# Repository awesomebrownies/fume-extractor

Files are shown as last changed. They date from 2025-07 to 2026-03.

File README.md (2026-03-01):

# Fume Extractor

A Travel packable fume-extractor for electronic prototyping inspired by Rogue One movie props. 

***Why?*** Many soldering iron fume extractors are low quality and merely push away fumes rather than properly filter them. The capsule design ensures that all air moves through a thick layer of **active carbon granules**, not some cheap foam. In addition, the HEPA filter will deal with any particulates that could irritate the lungs.

## Key Features

It provides **3 spares** of quick-swap carbon capsules with HEPA filters to provide **2 stage filtering**. The microcontroller has an external mount with warning lights when **failed filtering of Volatile Organic Compounds (VOCs)** is detected from a dedicated sensor. The vacuum tube is supported by a gooseneck arm for easily getting up close to fumes.

<p float="left">
  Screenshot from 2025-08-06 09-17-03
  Screenshot from 2025-07-29 23-48-41
</p>

## How to Assemble

There are two parts to this.
* Ordering BOM
* 3d Printing Parts (check CAD folder)
* Putting it all together

Let's skip over to putting it together.

### Wiring up the PWM fans to the Microcontroller (Rpi-Pico)

Refer to the wiring diagram below:

Screenshot from 2025-07-29 23-48-41

### Putting together the print

The capsules are in a couple of pieces, and you'll need a screw and a nut for each of the parts.

* First, insert the fan inside, with the wires on the accessible side for hooking up to the microcontroller. Use the screws available inside of the package for the fans
* Then, put a mesh between the fan and the rest of the capsule on the next part. You'll need two M2 screws and nuts
* Finally, pour the bag of carbon granules inside, and insert the HEPA filter at the end. As before, you'll need two M2 screws and nuts

### Final Steps

* Flashing firmware

To flash the firmware, open up the Arduino IDE, and copy and paste the code from the repository to the pico

## Project Bill of Materials

**Total Cost: $149.68**

## Electronics – $62.70

| Component | Quantity | Price | Link | Notes |
| --- | --- | ----- | --- | ----- |
| Air Quality Sensor | 1 | $6.20 | [DigiKey](https://www.digikey.com/en/products/detail/sensirion-ag/SGP40-D-R4/12820418) | |
| PWM Ventilation Fans | 3 | $48.00| [Amazon](https://www.amazon.com/Noctua-NF-A4x10-5V-PWM-Premium/dp/B07DXS86G7) | |
| Raspberry Pi Pico | 1 | $4.00 | [DigiKey](https://www.digikey.com/en/products/detail/raspberry-pi/SC0915/13684020) | |
| Rotary Encoder w/ Switch  | 1 | $4.50 | [DigiKey](https://www.digikey.com/en/products/detail/alps-alpine/EC11E09244BS/21721622) | |

## Fume Hood – $24.99

| Component | Quantity | Price  | Link | Notes |
| --- | --- | --- | --- | ----- |
| 19" Gooseneck Arm | 1 | $12.99 | [Amazon](https://www.amazon.com/Gator-Frameworks-Gooseneck-Microphones-GFW-MIC-GN19/dp/B01CUR5DU2) | |
| Flexible Hose | 1 | $12.00 | [Amazon](https://www.amazon.com/Flexible-Central-Vacuum-Installation-Hose/dp/B0CLH8M5JQ?source=ps-sl-shoppingads...) | |

## Filtering Elements – $61.99

| Component | Quantity | Price  | Link | Notes |
| --- | --- | --- | --- | ----- |
| Vacuum Washable HEPA Filter | 3 | $15.99 | [Amazon](https://www.amazon.com/SunSare-CPA1725-RYH-Vacuum-Filter-3PCS/dp/B0DQ8STYNL) | |
| Bag of Carbon Granules | 1 | $46.00 | [Amazon](https://www.amazon.com/AC-Infinity-Australian-Replacement-Hydroponics/dp/B0CFCKFPHR?th=1) | |

## Mechanics – $0.00

| Component | Quantity | Price | Link | Notes |
| ---| --- | ----- | ---- | --- |
| Springs | 2 | - | - | Already purchased |
| 3D Prints | - | - | - | Using printing legion  |
| Heatset M2 Inserts | 2  | - | - | Already purchased |

## Cost Summary

| Section | Cost |
| --- | --- |
| Electronics | $62.70 |
| Fume Hood | $24.99 |
| Filtering Elements  | $61.99 |
| Mechanics | $0.00 |
| **Total** | **$149.68** |

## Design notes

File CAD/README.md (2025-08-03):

You can access the full 3d model all put together on Onshape through the link below.
https://cad.onshape.com/documents/335012112260812ccd2665ef/w/8a5731f2524418035e58fee5/e/4748e060fb0672c7618c2129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

OR

Access the full fume extractor .step file by downloading "Full Fume Extractor.step"

Here are all the essential files you need to print the fume exctractor!

Print all of these once, except the following should be printed TWO times

- Spring Cap

The following should be printed FOUR times

- Spring Clamp

The following should be printed SIX times

- Cylinder Holder
- Fan Filter Bottom Cap
- Fan Filter Center Cylinder
- Fan Filter Fan Holder
- Fan Filter Top Cap

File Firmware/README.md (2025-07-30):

# Fume-Extractor Reference Guide

Since I don't have the actual board and components, it's impossible to test the code I will create. I've linked together a network of relevant tutorials I will be using to problem shoot.

The firmware will be written in C++ using the Arduino IDE & many libraries.

## Parts

- How to control PWM on fans
- Reading button presses

### PWM on fans

https://fdossena.com/?p=ArduinoFanControl/i.md

### Reading Buttons

Since my buttons are connected to GND and a pin, I need to set the GPIO pins to PULL UP mode, and then detect the current state with the digital read function

```
pinMode(buttonPin, INPUT_PULLUP);
//and also
int buttonState = digitalRead(buttonPin);
```

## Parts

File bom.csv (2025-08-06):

Category | Component | Quantity | Price | Link | Notes
Electronics | Air Quality Sensor | 1 | 6.2 | https://www.digikey.com/en/products/detail/sensirion-ag/SGP40-D-R4/12820418
Electronics | PWM Ventilation Fans | 3 | 48.0 | https://www.amazon.com/Noctua-NF-A4x10-5V-PWM-Premium/dp/B07DXS86G7
Electronics | Raspberry Pi Pico | 1 | 4.0 | https://www.digikey.com/en/products/detail/raspberry-pi/SC0915/13684020
Electronics | Rotary Encoder w/ Switch | 1 | 4.5 | https://www.digikey.com/en/products/detail/alps-alpine/EC11E09244BS/21721622
Fume Hood | 19" Gooseneck Arm | 1 | 12.99 | https://www.amazon.com/Gator-Frameworks-Gooseneck-Microphones-GFW-MIC-GN19/dp/B01CUR5DU2
Fume Hood | Flexible Hose | 1 | 12.0 | https://www.amazon.com/Flexible-Central-Vacuum-Installation-Hose/dp/B0CLH8M5JQ
Filtering Elements | Vacuum Washable HEPA Filter | 3 | 15.99 | https://www.amazon.com/SunSare-CPA1725-RYH-Vacuum-Filter-3PCS/dp/B0DQ8STYNL
Filtering Elements | Bag of Carbon Granules | 1 | 46.0 | https://www.amazon.com/AC-Infinity-Australian-Replacement-Hydroponics/dp/B0CFCKFPHR?th=1
Mechanics | Springs | 2 | 0.0 | - | Already purchased
Mechanics | 3D Prints | - | 0.0 | - | Using printing legion
Optional Tools (Not in BOM) | Wire Spool | 5 | 25.98 | https://www.microcenter.com/product/456250/adafruit-industries-hook-up-wire-spool-set-(22awg-solid-core-25-ft) | Personally recommended
Optional Tools (Not in BOM) | Wire Stripper | 1 | 21.97 | https://www.amazon.com/Self-Adjusting-Stripper-Klein-Tools-11061/dp/B00CXKOEQ6 | Personally recommended

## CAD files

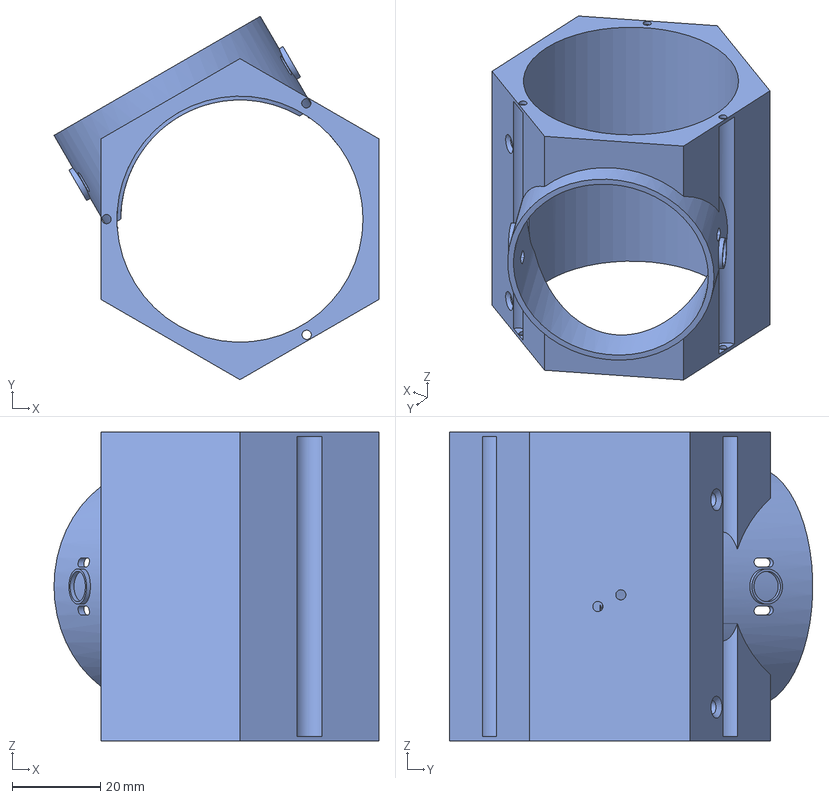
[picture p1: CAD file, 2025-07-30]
CAD/Main Body.step
73.6 x 82.3 x 70.0 mm

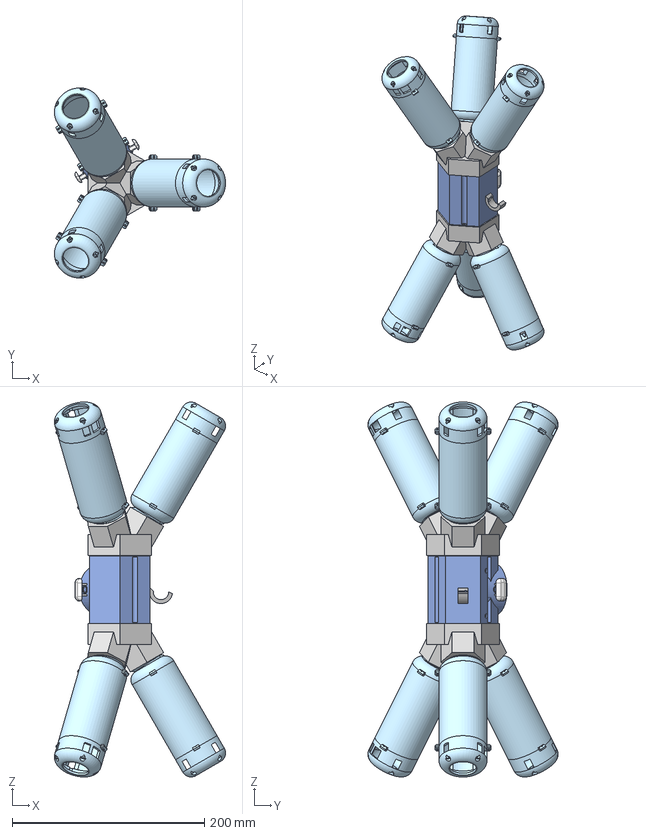
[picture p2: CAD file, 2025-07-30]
CAD/Full Fume Extractor.step
178.0 x 197.7 x 389.8 mm

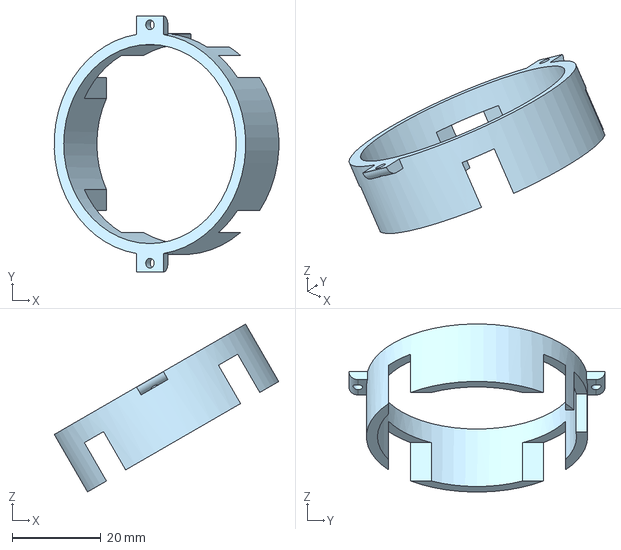
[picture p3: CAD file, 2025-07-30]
CAD/Fan Filter Fan Holder (Print x6).step
50.7 x 57.9 x 37.9 mm

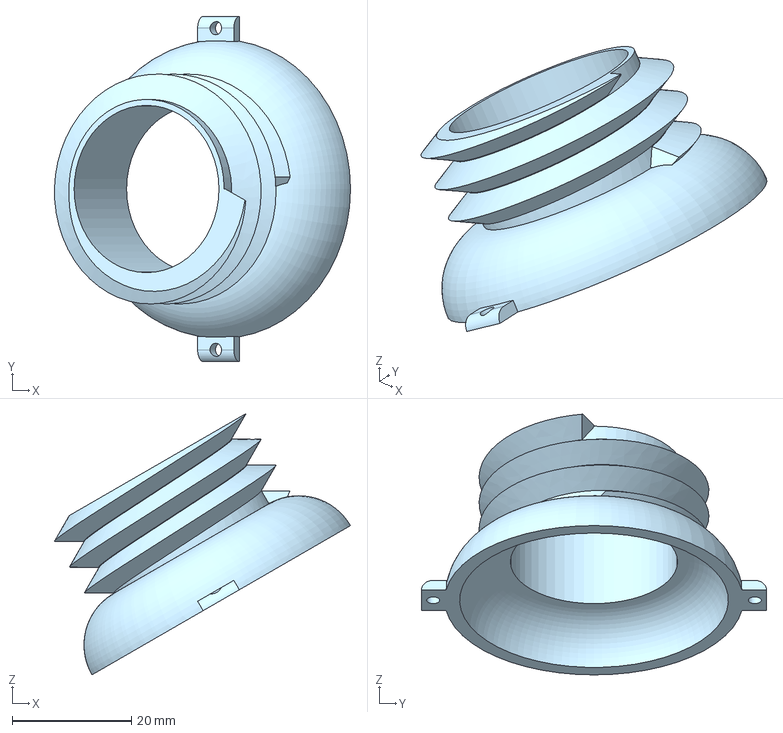
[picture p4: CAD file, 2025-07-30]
CAD/Fan Filter Top Cap (Print x6).step
49.6 x 57.8 x 43.7 mm

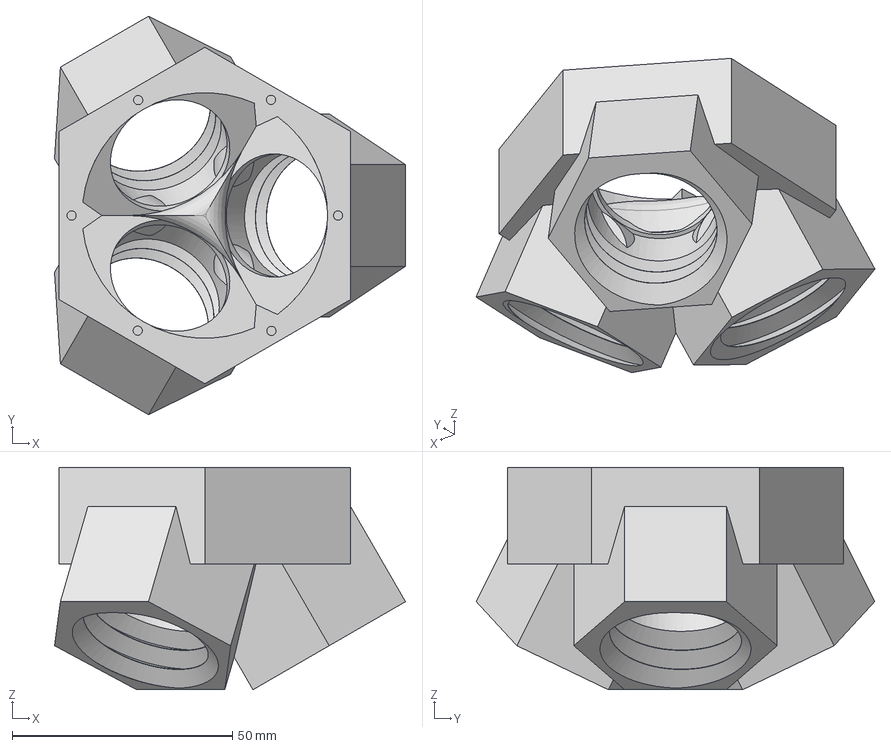
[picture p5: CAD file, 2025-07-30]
CAD/Cylinder Holder (Print x2).step
79.7 x 90.5 x 50.5 mm

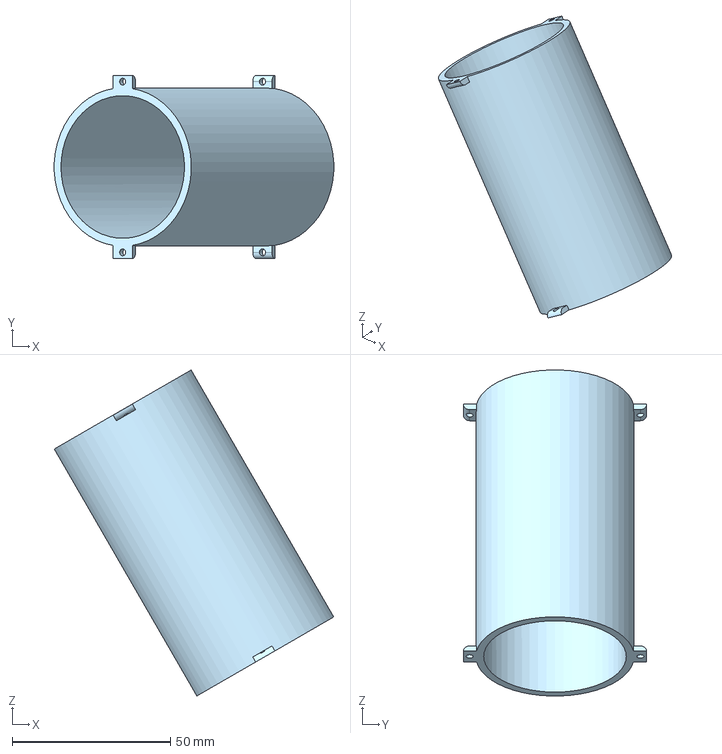
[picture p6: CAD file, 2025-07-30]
CAD/Fan Filter Center Cylinder (Print x6).step
88.2 x 57.9 x 102.9 mm

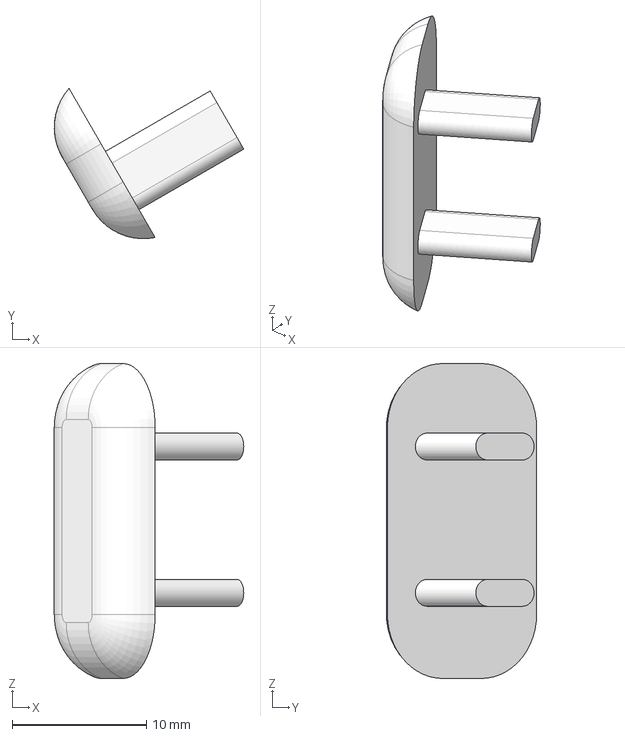
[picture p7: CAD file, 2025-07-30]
CAD/Spring Cap (Print x2).step
14.1 x 11.2 x 23.4 mm

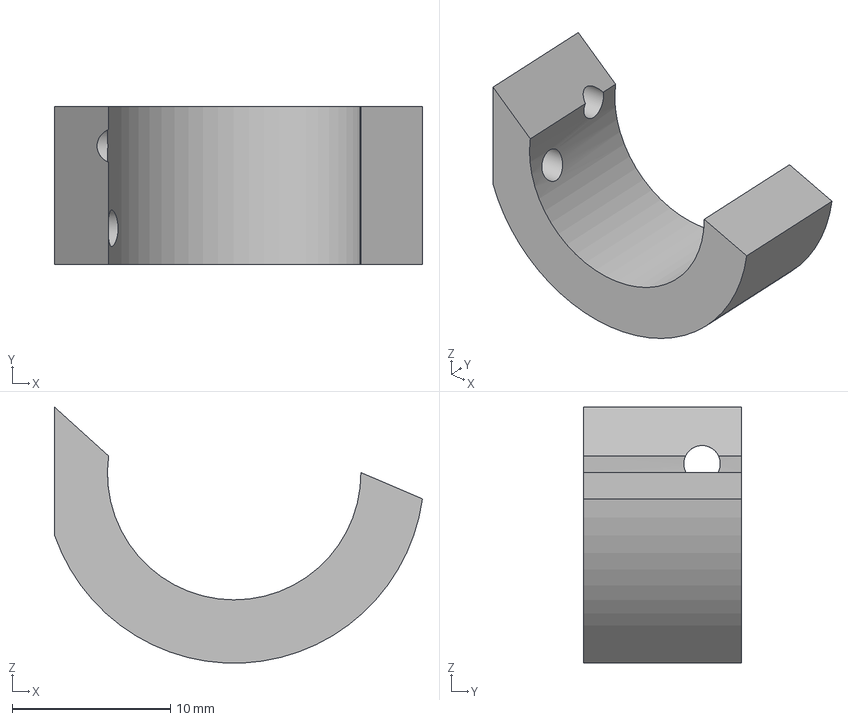
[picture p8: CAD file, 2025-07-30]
CAD/Gooseneck Clamp.step
23.2 x 10.0 x 16.2 mm

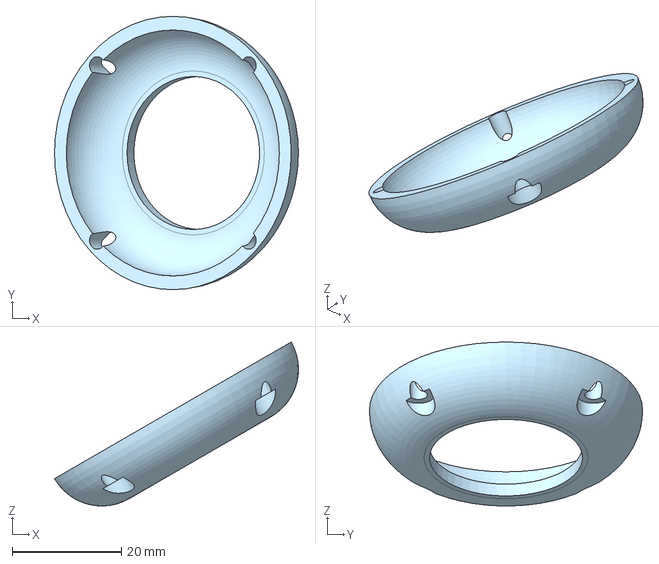
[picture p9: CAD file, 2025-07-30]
CAD/Fan Filter Bottom Cap (Print x6).step
44.6 x 50.0 x 30.0 mm

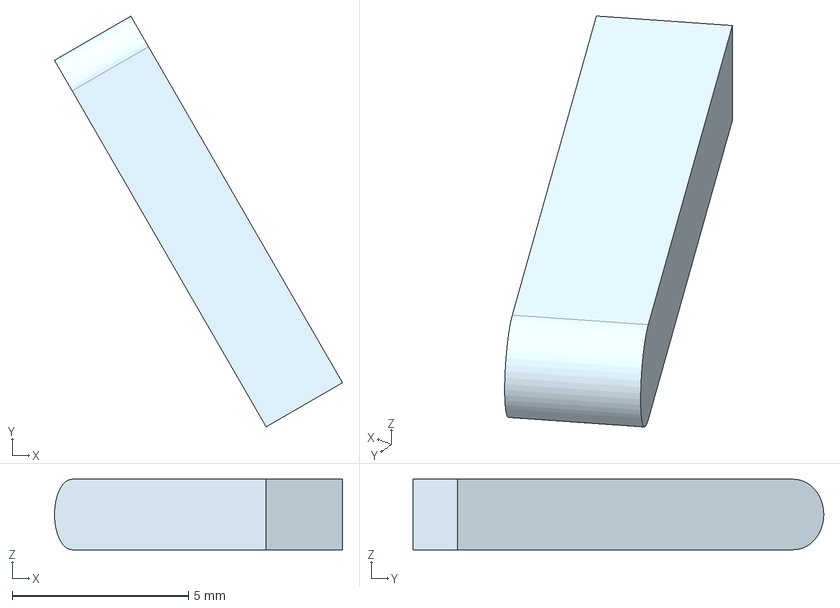
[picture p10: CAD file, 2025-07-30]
CAD/Spring Clamp (Print x4).step
8.17 x 11.6 x 2.00 mm

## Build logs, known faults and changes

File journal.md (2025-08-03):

---
title: "Fume Extractor"
author: "Evan Brown"
description: "Apocalyptic rig with a two hand adjustable fume hood w/ hot-swappable gas active carbon filtering canisters"
created_at: "2024-03-20"
---

**26 total hours spent on the project**

## July 1st

I plan on this being a decorative project with a high level of functionality, modularity, and somethign easily packable. While looking around on the market, I've found little to no high quality fume extractors at an affordable price.

The decorative plan is to buy acrylic paints and cut outlines into paper as a stencil.

**3 hours:** research & model layout

## July 2nd

I'm planning to embed the 5v fan controller inside of the active carbon filter granule container. It needs to be at the end of the stage 2 filter to avoid clogging. I had to research how to do screw-in containers in onshape, so that's a new thing I've learned! This model is split into two parts, and I'll need to research more on the fan mounts to properly embed holes.

**2 hours:** modeling

Screenshot from 2025-07-02 23-29-49

## July 3rd

I spent a lot of time making planes and certain hard to get points and pieces to create all of the geometry. One of the difficulties was merging together all of the screw holes, and I had to refactor it later when I had messed up and created multiple parts for something that should only be one.

The overall outline shape is complete now. My plan is to have the top three cylinders as the active carbon backup containers when the volatile element sensor indicates required replacement. I've been brainstorming a spring mechanism for securing the vacuum hose to the extractor, and that's where I'll be heading next.

**6 hours:** modeling

Screenshot from 2025-07-03 19-24-34

## July 4th

Today I finished the 3d model. I'll be focusing on electronics going forward. The best approach I theorized for securing the vacuum hose was using springs for a friction fit that can be push released. You can see it in the image below.

Screenshot from 2025-07-18 00-03-56

**3 hours** modeling

## July 17th

The fan has wires for PWM and power. I've created holes within the cylinders for the wires to go out of, as well as screw holes to secure the fans.

Screenshot from 2025-07-18 00-00-55

**1 hour:** modeling

## July 18th

Mostly spent on further material sourcing, the perfect filter showed itself to me. Exactly 25mm in diameter, this HEPA particulate filter is machine washable and the exact size needed. I have also found SSD1306 compatible OLED displays on digikey using the I2C interface, allowing for me to easily monitor the volatile organic compounds exiting and entering using the VOC sensor -SGP40-.

Screenshot from 2025-07-18 14-06-25

I've gone over the maximum budget given for a 6 point project, therefore I'm going to be shelling out my own money for anything over the budget. I really want to see this project succeed!

**3 hours** sourcing materials

## July 18th *Night

The HEPA filter needed a good spot to be placed, I decided I would tackle two problems at once. It's very difficult to print a cylinder in one piece, and the top part of the cylinder would be a challenge. So I split it up into another piece, while also adding bolts to secure the HEPA filters in that place. This is the ideal position, since I can print block-off sheets on the un-used filters if need be, to preserve the carbon granules, while on the active canisters, it's the first stage, making the carbon granules (which need to be replaced unlike the machine washable HEPA filters) last longer.

Screenshot from 2025-07-18 23-06-14

**1 hour** modeling

## July 29th

I've just gotten a break day from my part time 37hr a week job, so I'm getting some motivation to push through to the final product. The hose clamp extrusion has been polished up, and I've removed unnecessary material for better airflow. I've also added a spot for the gooseneck arm to secure to, which in turn will give rigidity to the vacuum hose. It has two M2 screws and I'll use nuts on the other side.

Screenshot from 2025-07-29 13-55-43

**3 hours** modeling

## July 29th Night*

The final touches were made and its off to submission land! I've added screw holes for the raspberry pi pico to mount to, as well as additional separation pieces to prevent the fan sucking carbon granules. The final addition is the hook which will secure the gooseneck arm. Unfortunately due to the nature of hoses and gooseneck arms I cannot put them in a program like cad unless I want it to look ridiculous. I've just put all of the parts together, and it's looking fantastic!

Screenshot from 2025-07-29 21-21-22

**4 hours** getting parts & modeling

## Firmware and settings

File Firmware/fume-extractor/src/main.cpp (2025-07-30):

#include <Arduino.h>

const int pwmPins[3] = {2, 3, 4};
const int tachoPins[3] = {5, 6, 7};

volatile unsigned long pulseCounts[3] = {0, 0, 0};
unsigned long lastCheck = 0;
int rpm[3] = {0, 0, 0};

void tacho0() { pulseCounts[0]++; }
void tacho1() { pulseCounts[1]++; }
void tacho2() { pulseCounts[2]++; }

void setup()
{
  analogWriteFreq(25000);
  for (int i = 0; i < 3; i++)
  {
    pinMode(pwmPins[i], OUTPUT);
    analogWrite(pwmPins[i], 128);
    pinMode(tachoPins[i], INPUT_PULLUP);
  }
  attachInterrupt(digitalPinToInterrupt(tachoPins[0]), tacho0, FALLING);
  attachInterrupt(digitalPinToInterrupt(tachoPins[1]), tacho1, FALLING);
  attachInterrupt(digitalPinToInterrupt(tachoPins[2]), tacho2, FALLING);
  Serial.begin(115200);
}

void loop()
{
  if (millis() - lastCheck >= 1000)
  {
    noInterrupts();
    unsigned long p[3] = {pulseCounts[0], pulseCounts[1], pulseCounts[2]};
    for (int i = 0; i < 3; i++)
      pulseCounts[i] = 0;
    interrupts();

    for (int i = 0; i < 3; i++)
      rpm[i] = (p[i] * 60) / 2;

    Serial.print("RPM: ");
    Serial.print(rpm[0]);
    Serial.print(" ");
    Serial.print(rpm[1]);
    Serial.print(" ");
    Serial.println(rpm[2]);

    lastCheck = millis();
  }
}
